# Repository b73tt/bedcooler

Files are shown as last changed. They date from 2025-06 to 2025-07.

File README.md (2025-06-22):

# Bed Cooler

This is a test prototype of a home made bed cooler, that blows cold air at your feet when they get too hot. I don't know if it'll work.

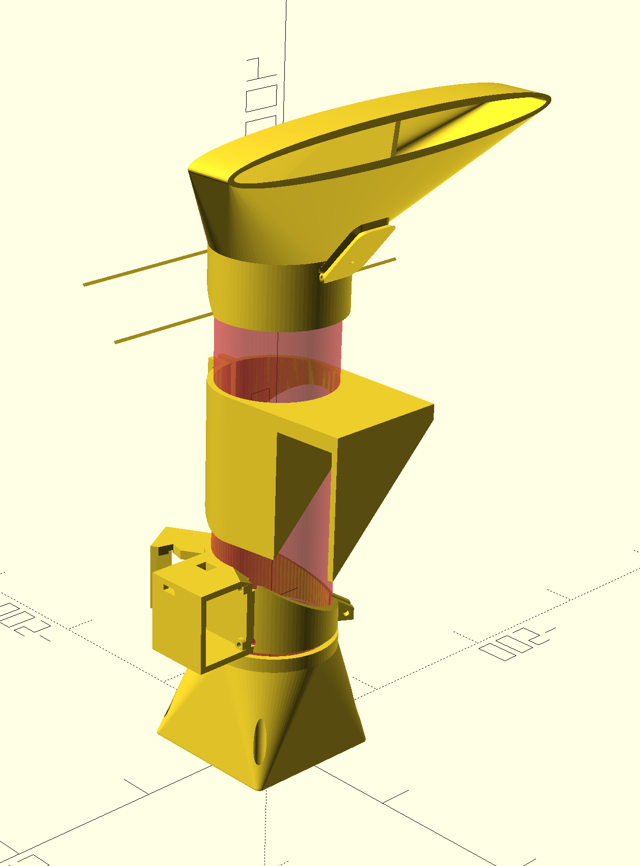
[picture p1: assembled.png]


The STL files expect a MALM bed from Ikea and a 75mm OD PVC pipe, cut to an appropriate length.
For my MALM bed and Ikea mattress, this length is 28cm.

BedCooler.ino is Arduino code for the thermostat, you will need to specify your Wifi details and local MQTT server address.

I'm using a Wemos D1 mini clone microcontroller, a DHT11 temperature sensor, and a L298N motor controller.

This project is in no way ready for you to just build one unless you're comfortable with tweaking all the parts.

## 3D printing intended orientation

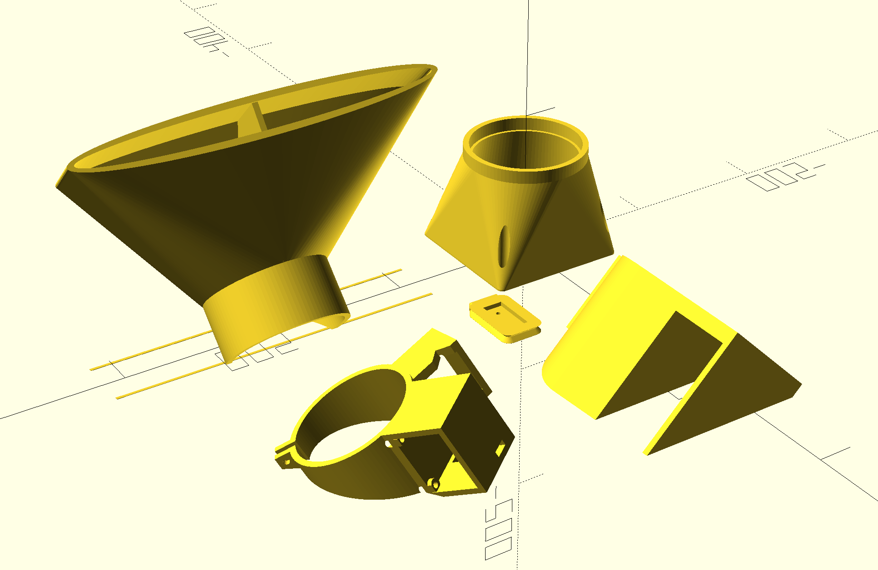
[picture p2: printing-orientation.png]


## MQTT topics

**BedCooler/LWT**: will write Online and Offline as appropriate

**BedCooler/SetTriggerTemp**: set the degrees Celsius to turn the fan on at

**BedCooler/SetTriggerHumidity**: set the relative humidity (%) to turn the fan on at

**BedCooler/SetMode**: set this as On, Off, or Auto.
On turns on the fan, Off turns off the fan, Auto turns on the fan when the temperature is greater than the Trigger temp (off otherwise)

**BedCooler/SetSpeed**: Takes a PWM value between 1-255. On my motor controller/fan this makes a whining noise so I'm instead supplying the L298N with between 5-12 volts of power in order to set the speed.

**BedCooler/Temperature**: In Auto mode, this will publish the current temperature every 30 seconds

**BedCooler/Humidity**: In Auto mode, this will publish the current humidity every 30 seconds

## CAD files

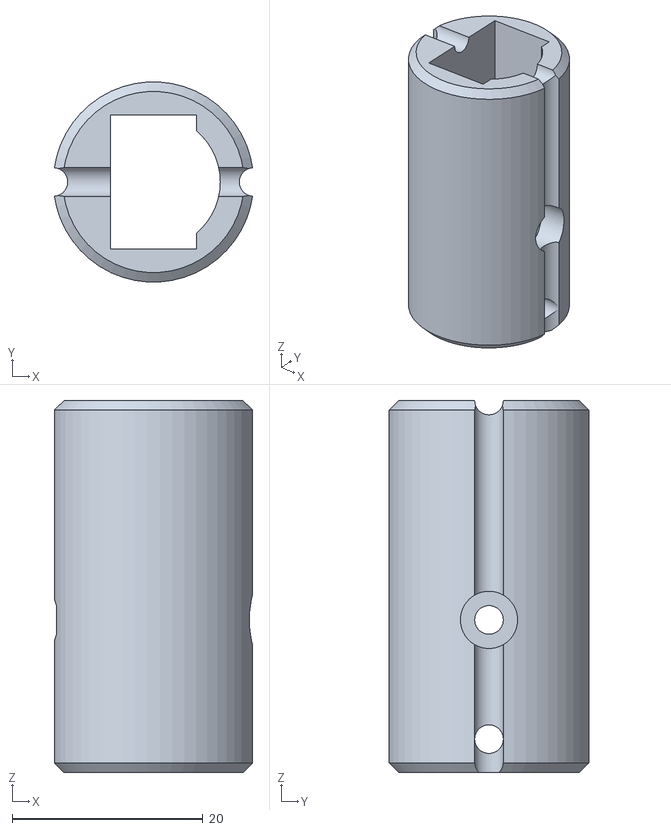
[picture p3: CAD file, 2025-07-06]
Sensor.stl
20.8 x 21.0 x 39.0

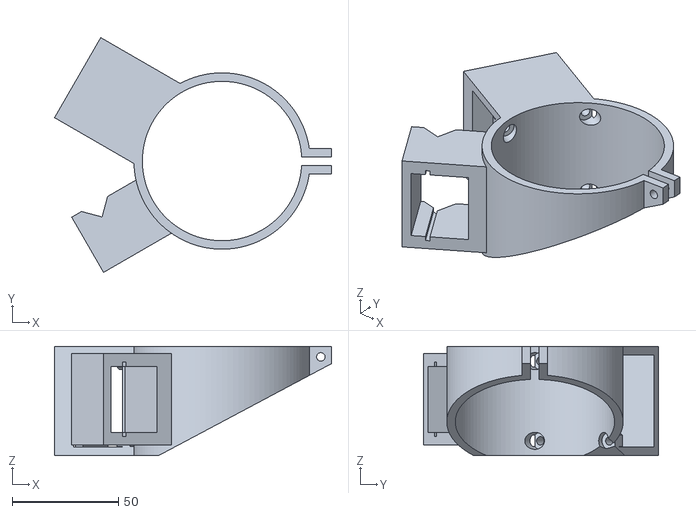
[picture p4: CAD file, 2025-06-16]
Electronics.stl
130.4 x 110.5 x 51.5

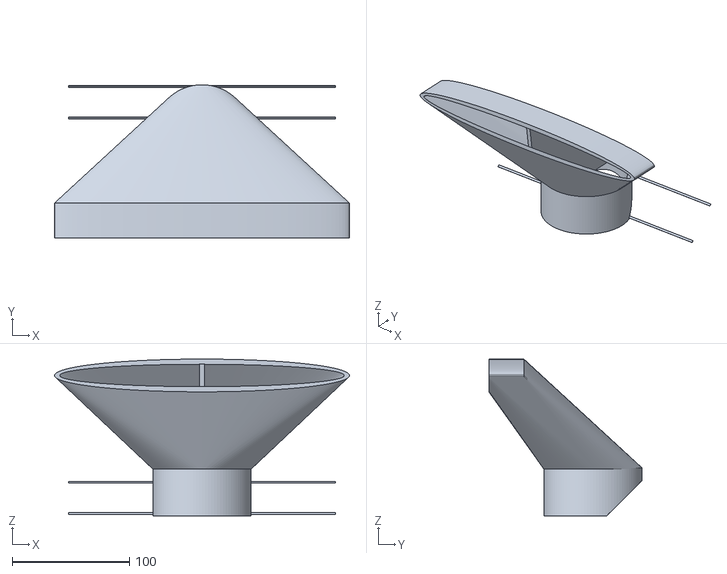
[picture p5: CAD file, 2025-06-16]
Head.stl
252.0 x 131.0 x 134.0

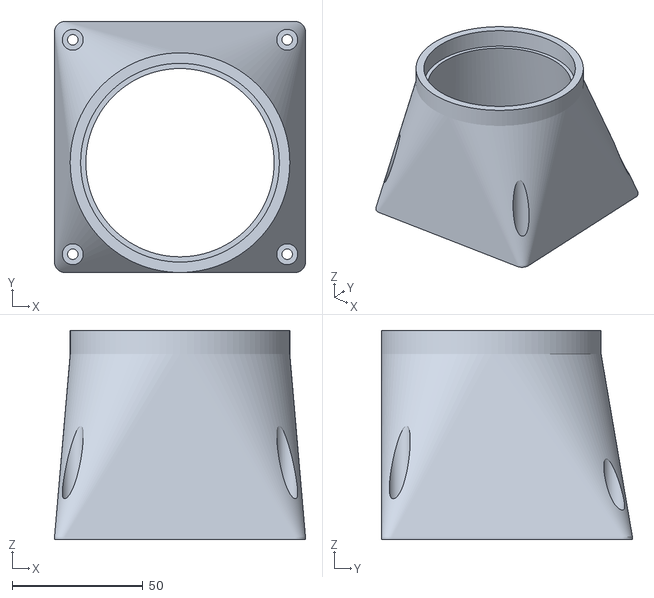
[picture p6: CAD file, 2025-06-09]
Fan.stl
96.0 x 96.0 x 80.0

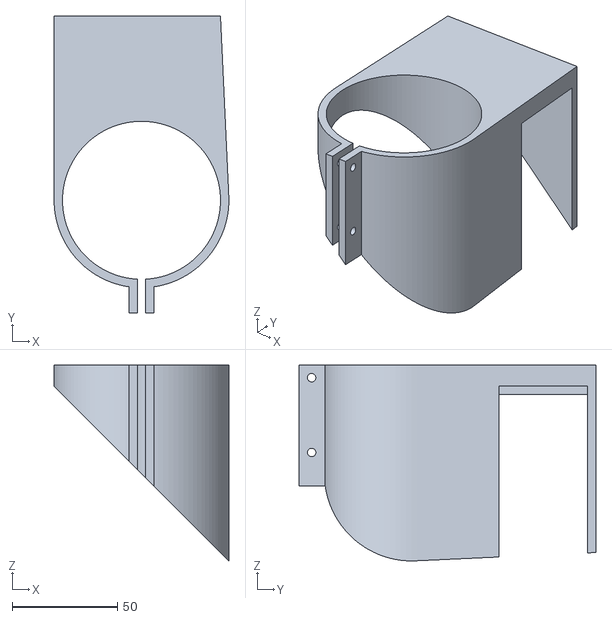
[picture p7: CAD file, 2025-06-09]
BedHook.stl
83.0 x 141.0 x 93.0

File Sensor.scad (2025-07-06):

wireOD = 3;
sensorMountX = 14;
sensorMountY = 30;
sensorMountZ = 9;
sensorMountScrewSize = 3;
wallThickness = 2;
chamferSize=1;
$fn=50;

difference() {
    // Surround to protect the sensor from feet
    
    hull() {
        cylinder(h = 1, r=sensorMountX/2+wallThickness+wireOD/2-chamferSize);
        translate([0,0,chamferSize])
        cylinder(h = sensorMountY+wallThickness*3+wireOD-chamferSize*2, r=sensorMountX/2+wallThickness+wireOD/2);
        translate([0,0,sensorMountY+wallThickness*3+wireOD-chamferSize])
        cylinder(h = 1, r=sensorMountX/2+wallThickness+wireOD/2-chamferSize);
    }
        
    // internal platform for sensor
    translate([0, 0, 0])
    difference() {
        cylinder(h = sensorMountY+wallThickness*3+wireOD, r=sensorMountX/2);
        rotate([0,0,90])
        translate([-(sensorMountX/2+wallThickness+wireOD/2), sensorMountZ/2, 0])
        cube([sensorMountX+wallThickness*3+wireOD, sensorMountX/2+wallThickness+wireOD/2, sensorMountY+wallThickness*3+wireOD]);
    }
    
    // cutout for sensor
    rotate([90,0,90])
    translate([-sensorMountX/2,0,-sensorMountZ/2])
    cube([sensorMountX, sensorMountY+wallThickness*3+wireOD, sensorMountZ]);
    
    // vertical wire slots
    translate([sensorMountX/2+wallThickness+wireOD/2,0,0])
    cylinder(h=sensorMountY+wallThickness*3+wireOD, r=wireOD/2);
    translate([-(sensorMountX/2+wallThickness+wireOD/2),0,0])
    cylinder(h=sensorMountY+wallThickness*3+wireOD, r=wireOD/2);
    
    // horizontal wire slots
    translate([-(sensorMountX/2+wallThickness+wireOD/2),0,wireOD/2+wallThickness])
    rotate([0,90,0])
    cylinder(h=sensorMountX+wallThickness*2+wireOD, r=wireOD/2);
    
    translate([-(sensorMountX/2+wallThickness+wireOD/2),0,sensorMountY+wallThickness*3+wireOD])
    rotate([0,90,0])
    cylinder(h=sensorMountX+wallThickness*2+wireOD, r=wireOD/2);
    
    //screw hole to hold sensor
    translate([-(sensorMountX/2+wallThickness+wireOD/2),0,wallThickness*3+wireOD+sensorMountX/2])
    rotate([0,90,0]) {
        cylinder(h=sensorMountX+wallThickness*2+wireOD, r=sensorMountScrewSize/2);
        
        //nut
        #cylinder(h=sensorMountScrewSize+1, r=sensorMountScrewSize, $fn=6);
        
        // screw access
        translate([0, 0, sensorMountX+wallThickness])
        cylinder(h=wireOD+wallThickness, r=sensorMountScrewSize);
    }
    
    
}

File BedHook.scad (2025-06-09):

pipeOD = 75;
pipeOverlap = 10;
pipeClampSize = 12;
pipeClampScrewSize = 4;
wallThickness = 4;

bedDepth = 42;

$fn=100;

difference() {
union() {
difference() {
    hull() {
        translate([0,0,-pipeOD*1.5])
        cylinder(h=pipeOverlap+pipeOD*1.5, r=pipeOD/2+wallThickness);

        translate([-pipeOD/2-wallThickness,0,-pipeOD*1.5])
        cube([pipeOD+wallThickness, bedDepth+pipeOD/2+wallThickness*2, pipeOverlap+pipeOD*1.5]);
    }
    translate([0,0,-pipeOverlap-pipeOD*1.5])
    cylinder(h=pipeOverlap*2+pipeOD*1.5, r=pipeOD/2);
    translate([-pipeOD/2-wallThickness, pipeOD/2+wallThickness, -pipeOverlap-pipeOD*1.5])
    #cube([pipeOD+wallThickness*2, bedDepth, pipeOverlap+pipeOD*1.5]);
    
    //pipe clamp split
    translate([-wallThickness/2, -pipeOD/2-wallThickness,-pipeOD*1.5])
    cube([wallThickness, wallThickness*2, pipeOverlap+pipeOD*1.5]);
}

// pipe clamp

for (i=[-wallThickness, wallThickness]) {
    translate([i-wallThickness/2, -pipeOD/2-wallThickness-pipeClampSize,-pipeOD*1.5])
    difference() {
        cube([wallThickness, pipeClampSize+wallThickness, pipeOverlap+pipeOD*1.5]);
        for (j=[pipeOD*1.5+wallThickness, pipeOD+pipeOverlap-wallThickness]) {
            translate([0, pipeClampSize/2, j])
            rotate([0,90,0])
            #cylinder(h=wallThickness,r=pipeClampScrewSize/2);
        }
    }
}
}

// angled base for 3d printing
translate([-pipeOD/2-wallThickness,0,0])
rotate([0,45,0])
translate([0,-pipeOD/2-pipeClampSize-wallThickness, -pipeOverlap-pipeOD])
cube([pipeOD*2, pipeOD+bedDepth+wallThickness*5+pipeClampSize, pipeOverlap+pipeOD]);


}

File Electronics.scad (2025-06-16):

mcX=43.5;
mcY=43.5;
mcZ=30;
mcScrewDiameter=4;
mcScrewInset=3;
mcBottomClearance=3;
mcCornerThickness=2;

espX=35;
espY=30;
espZ=25;

pipeOD=75.5;
wallThickness=4;
clampLength=10;
clampScrew = 4;

$fn=100;

difference() {
    union() {
        //pipe
        cylinder(h=mcX+wallThickness*2, r = pipeOD/2+wallThickness);
        //pipe clamp
        rotate([0,0, -90])
        translate([-wallThickness*1.5,0,0])
        cube([wallThickness*3, pipeOD/2+wallThickness+clampLength, mcX+wallThickness*2]);
        
        //mc outside box
        rotate([0,0,-30])
        translate([-pipeOD/2, -mcX/2, 0])
        rotate([0,-90,0])
        translate([wallThickness, 0, 0])
        difference() {
            translate([-wallThickness, -wallThickness, -wallThickness])
            cube([mcX+wallThickness*2, mcY+wallThickness*2,, mcZ+mcBottomClearance+wallThickness*3]);
            
        }

        //esp negative
        rotate([0,0,30])
        translate([-pipeOD/2-wallThickness, -espX/2, wallThickness-espZ+mcZ])
        rotate([0,-90,0])
        difference() {
            translate([-wallThickness, 0, -wallThickness])
            cube([espX+wallThickness*2, espY, espZ+wallThickness*3]);
            translate([wallThickness/2, 0, wallThickness])
            cube([espX-wallThickness, espY, espZ]);
            
            translate([-wallThickness,espY,-wallThickness+espX/2])
            rotate([45,0,0])
            cube([espX+wallThickness*2, 10, 10]);
            
            translate([0,0,espZ*.67+wallThickness])
            #cube([espX, espY,2]);
        }
        

    }
    
    //motor controller negative
    rotate([0,0,-30])
    translate([-pipeOD/2, -mcX/2, 0])
        rotate([0,-90,0])
        translate([wallThickness, -wallThickness, wallThickness]) {
            difference() {
                #cube([mcX, mcY+wallThickness*2, mcZ+mcBottomClearance]);
                for (x=[mcScrewInset, mcX-mcScrewInset]) {
                    for (y=[mcScrewInset, mcY-mcScrewInset]) {
                        translate([x, y+wallThickness, 0])
                        cylinder(h=mcBottomClearance, r=mcScrewDiameter);
                    }    
                }
            }
            for (x=[mcScrewInset, mcX-mcScrewInset]) {
                for (y=[mcScrewInset, mcY-mcScrewInset]) {
                    translate([x, y+wallThickness, -wallThickness*3]) {
                        cylinder(h=mcBottomClearance+wallThickness*3, r=mcScrewDiameter/2);
                        #cylinder(h=wallThickness*2, r=mcScrewDiameter);
                    }
                        
                }    
            }
            translate([-wallThickness, 10, mcBottomClearance])
            #cube([wallThickness, 10, wallThickness*2]);
            translate([0, 10, mcX-wallThickness*3])
            cube([wallThickness, 10, wallThickness*2]);
        }
    
    //pipe clamp negative
    translate([0,-wallThickness/2,0])
    cube([pipeOD, wallThickness, mcX+wallThickness*2]);
    cylinder(h=mcX+wallThickness*2, r = pipeOD/2);
            
    //pipe clamp screw
    translate([pipeOD/2+wallThickness+clampLength/2, 0, mcX+wallThickness*2-clampLength/2])
    rotate([90,0,0])
    translate([0,0,-wallThickness*1.5])
    cylinder(h=wallThickness*3, r=clampScrew/2);
            
    //angled base for 3D printing
    translate([-pipeOD*0.4, 0, 0])
    rotate([0,62,0])
    translate([0, -pipeOD/2-wallThickness,0])
    cube([pipeOD, pipeOD+wallThickness*4, pipeOD*2]);
}

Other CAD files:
Fan.scad
Head.scad

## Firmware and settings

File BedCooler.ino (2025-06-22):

#include <ESP8266WiFi.h>
#include <PubSubClient.h>
#include <DHT.h>

const char* ssid     = "wifi-ssid"; // Wifi details
const char* password = "wifi-password";
const char* mqtt_server = "mqtt"; // MQTT server

const int motorPin = D3;
const int motorSpeedPin = D2;

const int dhtPin = D1;
const int dhtType = DHT11;

// defaults, we can set these later (and have the MQTT server retain them)
byte fanspeed = 128;
float triggerTemp = 22.0;
int triggerHumidity = 70;

byte mode = 0; //0 = Off, 1= Auto, 2 = On

int iteration = 0;
WiFiClient espClient;
PubSubClient client(espClient);
DHT dht(dhtPin, dhtType);

void setup_wifi() {
  delay(10);
  // We start by connecting to a WiFi network

  WiFi.mode(WIFI_STA);
  WiFi.setHostname("BedCooler");
  WiFi.begin(ssid, password);

  while (WiFi.status() != WL_CONNECTED) {
    delay(500);
  }

  randomSeed(micros());
}

void callback(char* topic, byte* payload, unsigned int length) {
  //message 'payload' arrived to topic 'topic'

  char command[length + 1];
  memcpy(command, payload, length);
  command[length] = '\0';

  if (strcmp(topic, "BedCooler/SetTriggerTemp") == 0) {
    triggerTemp = atof(command);
    Serial.println("Setting trigger temp");
    Serial.println(triggerTemp);
  } else if (strcmp(topic, "BedCooler/SetTriggerHumidity") == 0) {
    triggerHumidity = atoi(command);
    Serial.println("Setting trigger humidity");
    Serial.println(triggerHumidity);
  } else if (strcmp(topic, "BedCooler/SetSpeed") == 0) {
    fanspeed = atoi(command);
    analogWrite(motorSpeedPin, fanspeed);
    Serial.println("Setting speed");
    Serial.println(fanspeed);
    
  } else if (strcmp(topic, "BedCooler/SetMode") == 0) {
    if (strcmp(command, "On") == 0) {
      mode = 2;
      digitalWrite(motorPin, HIGH);
      Serial.println("On mode");
    } else if (strcmp(command, "Off") == 0) {
      mode = 0;
      digitalWrite(motorPin, LOW);
      Serial.println("Off mode");
    } else if (strcmp(command, "Auto") == 0) {
      mode = 1;
      Serial.println("Auto mode");
    }
  }
}

void reconnect() {
  // Loop until we're reconnected
  digitalWrite(BUILTIN_LED, LOW);
  while (!client.connected()) {
    String clientId = "BedCooler";
    
    if (client.connect(clientId.c_str(), "BedCooler/LWT", 2, true, "Offline")) {
      client.publish("BedCooler/LWT", "Online", true);
      
      client.subscribe("BedCooler/SetTriggerTemp"); //26.5
      client.subscribe("BedCooler/SetTriggerHumidity"); //70
      client.subscribe("BedCooler/SetSpeed"); //128
      client.subscribe("BedCooler/SetMode"); //On Auto Off
    } else {
      delay(5000);
    }
  }
  digitalWrite(BUILTIN_LED, HIGH);
}

void setup() {
  pinMode(BUILTIN_LED, OUTPUT);
  pinMode(motorPin, OUTPUT);
  pinMode(motorSpeedPin, OUTPUT);
  digitalWrite(motorPin, LOW);
  analogWrite(motorSpeedPin, fanspeed);

  Serial.begin(9600);
  setup_wifi();

  client.setServer(mqtt_server, 1883);
  client.setCallback(callback);

  dht.begin();
  
}


void loop() {
  if (!client.connected()) {
    reconnect();
  }
  client.loop();
  delay(1000);
  

  if (iteration == 0) {

    if (mode == 1) {
      float temp = dht.readTemperature();
      int humidity = dht.readHumidity();
      
      Serial.println("Compare Temp/Humidity to Trigger");
      if (temp >= triggerTemp || humidity >= triggerHumidity) {
        digitalWrite(motorPin, HIGH);
        analogWrite(motorSpeedPin, fanspeed);
      } else {
        digitalWrite(motorPin, LOW);
      }
      
      Serial.println("Publish Temp and Humidity to MQTT");
      char result[10];
      dtostrf(temp, 2, 1, result);
      client.publish("BedCooler/Temperature", result, true);
      dtostrf(humidity, 2, 0, result);
      client.publish("BedCooler/Humidity", result, true);
    }
    
  }

  iteration = (iteration + 1) % 30;
}

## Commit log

2025-06-09 Inital commit
    [BedJetBedHook.scad, BedJetBedHook.stl, BedJetFan.scad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]
2025-06-09 first print files
    [BedJetBedHook.scad, BedJetHead.scad, BedJetHead.stl]
2025-06-16 Adding electronics and sensor housing, notes in Head
    [BedJetElectronics.scad, BedJetElectronics.stl, BedJetHead.scad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]
2025-06-16 Adding the Arduino code, including some more info in the README
2025-06-16 Generated some CAD images for what it looks like assembled and the printing orientation
2025-06-19 Renaming files as BedJet is a similar product that already exists
    [BedHook.scad, BedHook.stl, Electronics.scad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]
2025-07-06 Updated sensor housing - more appropriate for being in the bed
    [Sensor.scad, Sensor.stl]
